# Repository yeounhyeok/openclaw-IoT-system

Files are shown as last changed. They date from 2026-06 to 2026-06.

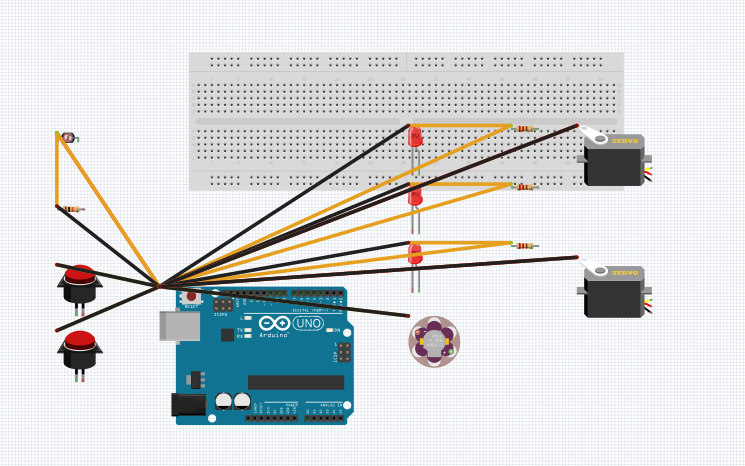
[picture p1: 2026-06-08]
docs/스크린샷 2026-06-02 164702.png

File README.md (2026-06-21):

# OpenClaw Physical Hand - Arduino 회로 프로젝트

제안서의 `OpenClaw Physical Hand: Arduino 기반 원격 버튼 제어 봇`을 실제로 구현하기 위한 Arduino 회로/펌웨어 프로젝트입니다.

> 이 프로젝트는 **실제 하드웨어 직접 제작**을 기준으로 정리되어 있습니다.
> `diagram.json`은 Wokwi에서 동작을 미리 확인하고 싶을 때 쓰는 보조 시뮬레이션 파일이며,
> CDS 부분만 Wokwi에 단순 2핀 CDS 부품이 없어 모듈형 광센서로 대체되어 있습니다.
> 실제 제작에서는 아래 설명대로 **다리 2개짜리 CDS 조도센서 + 분압저항** 구성을 사용합니다.

## 프로젝트 개요

- 메인 보드: Arduino Uno R4 WiFi + HC-05 Bluetooth 모듈
- 입력 디바이스 3종 / 출력 디바이스 4종으로 과제 조건(입력 3종↑ · 출력 3종↑) 충족
- 핵심 기능
  - 버튼으로 알람 토글
  - DHT22로 온습도 표시
  - **CDS 조도센서로 LCD 백라이트 자동 절전(주변이 어두워지면 백라이트 OFF)**
  - 서보모터로 PC 전원 버튼 누르기

## 포함 파일

- `sketch/sketch.ino` : Arduino 펌웨어 (메인 산출물)
- `README.md` : 회로 설명 / 핀맵 / 배선 / 동작 설명
- `docs/circuit_schematic.png` : 전체 연결 schematic 이미지 (보고서/HWP 첨부용)
- `docs/cds_divider.png` : CDS 조도센서 분압 회로 상세도
- `docs/*.svg` : 위 이미지의 벡터 버전 (확대해도 안 깨짐)
- `docs/OpenClaw.fzz` : **Fritzing 프로젝트 파일** (Fritzing에서 바로 열기)
- `docs/OpenClaw.fz` : 위 fzz 안의 스케치 XML (수정/검수용)
- `tools/make_schematic.py` : schematic 이미지 생성 스크립트
- `tools/make_fritzing.py` : Fritzing `.fzz` 생성 스크립트
- `diagram.json` : (선택) Wokwi 미리보기용 회로 배치 파일

## 회로도 (이미지)

보고서/발표 자료에 바로 붙일 수 있는 회로 이미지가 `docs/`에 있습니다.

- `docs/circuit_schematic.png` : Arduino Uno 중심 전체 연결도 (입력 4종 / 출력 4종이 한눈에)
- `docs/cds_divider.png` : 다리 2개짜리 CDS + 10kΩ 분압 회로 상세도

> 이미지는 Python `schemdraw`로 생성했습니다. 수정이 필요하면 아래처럼 재생성하면 됩니다.
> ```
> pip install schemdraw matplotlib
> python tools/make_schematic.py
> ```

## Fritzing 프로젝트 (docs/OpenClaw.fzz)

Fritzing에서 바로 열 수 있는 회로 파일도 포함되어 있습니다.

- 열기: Fritzing 실행 → File → Open → `docs/OpenClaw.fzz`
- 포함 부품(모두 Fritzing 기본 내장 core 부품): Arduino Uno, CDS(photoresistor) + 10k 분압, RGB용 LED 3개 + 220Ω 3개, 푸시버튼 2개, 피에조 부저, 서보 2개
- 배선은 핀맵표와 동일하게 연결되어 있습니다(점대점 배선). 열고 나서 부품을 드래그해 보기 좋게 정렬하면 됩니다.
- **참고**: DHT22 / I2C 1602 LCD 는 Fritzing 기본 core 부품에 없어서(별도 라이브러리 필요) 이 fzz에는 빠져 있습니다. 두 부품을 포함한 전체 구성은 `docs/circuit_schematic.png`(전체 연결도)와 `diagram.json`(Wokwi)에서 확인할 수 있습니다.
- 생성/수정: `python tools/make_fritzing.py` (core 부품의 moduleId·connectorId를 코드에서 직접 지정)

> 이 fzz는 Fritzing core 부품의 공식 moduleId/connectorId를 사용해 생성했고 XML 유효성은 검증했지만,
> 생성 환경에 Fritzing이 없어 화면 렌더링까지는 확인하지 못했습니다.
> 열었을 때 부품이 겹쳐 보이면 드래그로 정렬하면 되고, 혹시 누락/오류가 보이면 알려주세요.

## 입력 디바이스 3종

| # | 디바이스 | 연결 핀 | 역할 |
|---|---|---|---|
| 1 | DHT22 온습도 센서 | D2 | 온도/습도 환경값 입력 |
| 2 | Push Button | D3(ALARM) | 알람 토글 |
| 3 | **CDS 조도센서 (다리 2개)** | A0 | 주변 밝기 입력 → LCD 백라이트 자동 절전 |

## 출력 디바이스 4종

| # | 디바이스 | 연결 핀 | 역할 |
|---|---|---|---|
| 1 | Servo Motor | D9(PC 전원) | PC 전원 버튼 누르기 |
| 2 | 16×2 I2C LCD | A4(SDA), A5(SCL) | 온습도·알람·감지 상태 표시 |
| 3 | RGB LED | D12(R), D5(G), D6(B) | 정상/동작/이벤트/오류/알람 상태 표시 |
| 4 | Piezo Buzzer | D8 | 알림음 / 알람음 출력 |

## 전체 핀맵 (Arduino Uno 기준)

| 핀 | 연결 |
|----|---|
| D2 | DHT22 DATA |
| D3 | ALARM 버튼 (INPUT_PULLUP, 반대편 GND) |
| D5 | RGB LED G (220Ω 경유) |
| D6 | RGB LED B (220Ω 경유) |
| D8 | Buzzer (+) |
| D9 | PC 전원 서보 신호 |
| D12 | RGB LED R (220Ω 경유) |
| A0 | CDS 분압 노드 |
| A4 / A5 | LCD I2C SDA / SCL |
| 5V / GND | 공통 전원 / 접지 |

## CDS 조도센서 배선 (실제 제작 — 중요)

다리 2개짜리 CDS(광저항)는 단독으로 아날로그 값을 못 만들기 때문에 **분압 저항과 함께 분압 회로**로 연결합니다.

```
5V ──[ CDS ]──┬──[ 10kΩ ]── GND
              │
              └──> A0
```

- 밝을 때 : CDS 저항 ↓ → A0 전압(값) ↑
- 어두울 때 : CDS 저항 ↑ → A0 전압(값) ↓
- 코드에서 `analogRead(A0)` 값이 `LCD_DARK_THRESHOLD(=300)`보다 낮아지면 어두운 것으로 판단

> 분압 저항은 10kΩ을 기준으로 하며, 사용하는 CDS 사양에 따라 4.7k~10k 범위로 조정하면 됩니다.
> A0와 GND 사이에 CDS를 두는 반대 배선을 쓰면 밝고/어두움의 값 방향이 뒤집히므로,
> 그 경우 코드의 비교 부등호만 바꿔주면 됩니다.

## LCD 백라이트 자동 절전 기능 (핵심 기능)

스토리: 불을 끄고 잘 때 1602 LCD 백라이트가 너무 밝으면 눈이 부실 수 있으므로, 주변이 어두워지면 LCD 백라이트만 자동으로 끕니다.

- 사용 센서: CDS 조도센서 (다리 2개, A0 분압)
- 어두움 감지: `lcd.noBacklight();` 실행 → 배경 불빛 OFF
- 밝음 감지: `lcd.backlight();` 실행 → 배경 불빛 ON
- LCD 글씨/상태 정보는 유지되고, **배경 불빛만** 꺼지는 방식
- 시연 방법: 손으로 CDS를 가리면 LCD 백라이트가 꺼지고, 손을 떼면 다시 켜짐
- 친환경 IoT 포인트: 사용하지 않는 상황에서 표시장치 전력 소모와 빛 공해를 줄임

## 버튼 / RGB / 부저 동작

- `ALARM TOGGLE` 버튼 : 알람 ON/OFF 토글 (ON이면 부저 3회, RGB 보라)
- RGB LED 상태색
  - 초록 : 정상/대기
  - 보라 : 알람 ON
  - 파랑 : 원격(PC 전원) 명령 실행 / 감지 이벤트
  - 빨강 : DHT 읽기 오류

## 통신 조건 설명

실제 제작에서는 Arduino Uno R4 WiFi를 사용한다고 설명하면 됩니다.

- WiFi: Uno R4 WiFi 내장 무선 기능으로 Home Assistant WSS/HTTP 연동
- Bluetooth: HC-05 모듈로 Android 앱 근거리 제어
- PC 전원 누르기: Android Bluetooth 또는 Home Assistant WebSocket 명령을 받으면 PC 전원 서보가 동작

현재 `sketch/sketch.ino`에는 Uno R4 WiFi의 내장 BLE 코드, HC-05 Bluetooth UART 코드, WiFi 코드, Home Assistant WebSocket/HTTP 코드가 모두 들어가 있습니다. 단, Uno R4 WiFi의 내장 Bluetooth와 내장 WiFi는 같은 무선 모듈/안테나를 공유하므로 같은 순간에 둘을 동시에 켜는 방식은 사용할 수 없습니다.

WiFi와 Android Bluetooth 제어를 한 번에 시연하려면 HC-05 모듈을 추가하면 됩니다. 이 경우 Arduino는 내장 WiFi로 공유기/Home Assistant에 붙고, HC-05는 `Serial1`로 Android 명령을 전달합니다.

### Arduino 설정 플래그

`sketch/sketch.ino` 상단에서 통신 기능을 켜고 끕니다.

```cpp
#define ENABLE_BLE 0
#define ENABLE_HC05 1
#define ENABLE_WIFI 1
#define ENABLE_HA_HTTP 1
#define ENABLE_HA_WS 1
#define HA_USE_SSL 1
#define ENABLE_MQTT 0
```

- `ENABLE_BLE 1`: Uno R4 WiFi 내장 BLE로 Android 제어 사용
- `ENABLE_BLE 0`: Wokwi / 일반 Uno 시뮬레이션용
- `ENABLE_HC05 1`: HC-05 Bluetooth Classic 모듈로 Android 제어 사용
- `ENABLE_HC05 0`: HC-05 미사용
- `ENABLE_WIFI 1`: WiFi 공유기 연결 및 IP/RSSI 상태 확인
- `ENABLE_WIFI 0`: WiFi 연결 미사용
- `ENABLE_HA_HTTP 1`: Home Assistant HTTP REST API 연동 사용
- `ENABLE_HA_HTTP 0`: Home Assistant HTTP 미사용
- `ENABLE_HA_WS 1`: Home Assistant WebSocket으로 명령 이벤트 수신
- `ENABLE_HA_WS 0`: WebSocket 미사용, HTTP polling fallback 사용
- `HA_USE_SSL 1`: `https://` endpoint 사용
- `HA_USE_SSL 0`: 로컬 `http://` endpoint 사용
- `ENABLE_MQTT 1`: Home Assistant MQTT 명령/상태 연동 사용
- `ENABLE_MQTT 0`: MQTT 미사용

시연 모드는 아래처럼 나눕니다.

| 시연 | `ENABLE_BLE` | `ENABLE_HC05` | `ENABLE_WIFI` | `ENABLE_HA_HTTP` | `ENABLE_HA_WS` | `ENABLE_MQTT` |
|---|---|---|---|---|---|---|
| WiFi + HC-05 + HA WSS/HTTP | `0` | `1` | `1` | `1` | `1` | `0` |
| WiFi + HC-05 + HA HTTP polling | `0` | `1` | `1` | `1` | `0` | `0` |
| WiFi + HC-05만 | `0` | `1` | `1` | `0` | `0` | `0` |
| 내장 BLE 단독 시연 | `1` | `0` | `0` | `0` | `0` | `0` |
| WiFi 연결/IP 확인 | `0` | `0` | `1` | `0` | `0` | `0` |
| Home Assistant MQTT 제어 | `0` | `0` | `1` | `0` | `0` | `1` |
| Wokwi / 일반 Uno 시뮬레이션 | `0` | `0` | `0` | `0` | `0` | `0` |

즉, HC-05를 붙이면 과제에서 "WiFi와 Bluetooth가 한 번에 된다"를 같은 업로드로 보여줄 수 있습니다. 단, HC-05는 BLE가 아니라 Bluetooth Classic SPP입니다.

### Android 앱 연동값

내장 BLE를 사용할 때 Android 앱은 BLE Peripheral 이름 `OpenClaw-R4`를 찾아 연결합니다.

| 항목 | 값 |
|---|----|
| Service UUID | `19b10000-e8f2-537e-4f6c-d104768a1214` |
| Command Characteristic UUID | `19b10001-e8f2-537e-4f6c-d104768a1214` |
| Status Characteristic UUID | `19b10002-e8f2-537e-4f6c-d104768a1214` |

Android 앱은 Command Characteristic에 UTF-8 문자열을 write 하면 됩니다.

| 명령 | 동작 |
|---|---|
| `PC_POWER` | PC 전원 버튼 서보 1회 누름 |
| `ALARM_TOGGLE` | 알람 ON/OFF 토글 |
| `ALARM_ON` | 알람 ON |
| `ALARM_OFF` | 알람 OFF |
| `STATUS` | 상태값 갱신 |

Status Characteristic은 아래 같은 문자열을 read/notify 합니다.

```text
alarm=ON,temp=25.0,humidity=55
```

HC-05를 사용할 때 Android 앱은 BLE GATT가 아니라 Bluetooth Classic SPP로 연결합니다.

| 항목 | 값 |
|---|----|
| 장치 이름 | 보통 `HC-05` |
| 기본 PIN | 보통 `1234` 또는 `0000` |
| SPP UUID | `00001101-0000-1000-8000-00805F9B34FB` |
| 전송 방식 | BluetoothSocket output stream에 문자열 전송 |

Android 앱은 아래 명령 문자열을 HC-05로 보내면 됩니다. 줄바꿈(`\n`) 또는 세미콜론(`;`)을 붙여 보내면 가장 안정적입니다.

```text
PC_POWER
ALARM_TOGGLE
ALARM_ON
ALARM_OFF
STATUS
```

예:

```text
PC_POWER\n
```

MIT App Inventor로 앱을 만들 때는 [appinventor/OpenClawRemote.aia](appinventor/OpenClawRemote.aia)를 `Projects → Import project (.aia) from my computer`로 가져오면 됩니다. 수동으로 다시 만들거나 블록을 확인할 때는 [docs/appinventor_openclaw_remote.md](docs/appinventor_openclaw_remote.md)를 참고합니다. 구성은 `Pair HC-05`, `Connect HC-05`, `PC Power`, `Alarm Toggle`, `Alarm On/Off`, `Status`, custom command 입력으로 잡았습니다.

### HC-05 배선

Arduino 코드는 HC-05를 `Serial1`로 읽습니다. Uno R4 WiFi의 USB Serial과 `D0/D1` 하드웨어 Serial은 분리되어 있어서, USB로 Serial Monitor를 보면서 HC-05를 `D0/D1`에 연결해도 됩니다.

| HC-05 핀 | Arduino Uno R4 WiFi | 설명 |
|---|---|---|
| `VCC` | `5V` | 일반 HC-05 breakout 보드는 5V 입력 가능 |
| `GND` | `GND` | 공통 접지 |
| `TXD` | `D0 / RX1` | HC-05가 보내는 데이터 → Arduino 수신 |
| `RXD` | `D1 / TX1` | Arduino가 보내는 데이터 → HC-05 수신 |
| `EN` / `KEY` | 연결 안 함 | AT 설정 모드가 필요할 때만 사용 |
| `STATE` | 연결 안 함 | 연결 상태 확인용, 필수 아님 |

주의할 점:

- `TXD`와 `RXD`는 교차 연결합니다. `TXD -> RX1`, `RXD -> TX1`입니다.
- HC-05 breakout 보드는 `VCC`는 5V를 받아도, `RXD` 신호 입력은 3.3V 권장인 경우가 많습니다.
- Arduino `D1/TX1`에서 HC-05 `RXD`로 가는 선에는 전압 분배를 넣는 것이 안전합니다.
- 전압 분배 예: Arduino `D1/TX1` -- `1kΩ` -- HC-05 `RXD` -- `2kΩ` -- GND.
- HC-05 `TXD`에서 Arduino `D0/RX1`로 가는 선은 보통 바로 연결해도 Arduino가 HIGH로 인식합니다.
- 코드 기본 UART 속도는 `9600` baud입니다. 대부분 HC-05 기본 통신 속도와 같습니다.

### Home Assistant WSS/HTTP 연동값

MQTT broker 없이 Home Assistant API로 직접 연결합니다. HA → Arduino 명령은 `wss://ha.yeoun.org/api/websocket` 상시 연결로 받고, Arduino → HA helper 제어도 가능하면 WebSocket `call_service`로 되돌려 보냅니다. 온습도/상태 엔티티 업로드만 REST API `POST /api/states/...`를 느리게 사용합니다. Home Assistant API는 `Authorization: Bearer TOKEN` 인증이 필요합니다.

현재 Arduino 코드는 공개 엔드포인트 `https://ha.yeoun.org` 기준입니다.

민감정보는 `sketch/arduino_secrets.h`에 넣습니다. GitHub에는 올라가지 않도록 제외되어 있으니, 새 환경에서는 `sketch/arduino_secrets.example.h`를 `sketch/arduino_secrets.h`로 복사한 뒤 값을 채웁니다.

```cpp
#define SECRET_WIFI_SSID "SK_1194_2.4G"
#define SECRET_WIFI_PASSWORD "YOUR_WIFI_PASSWORD"

#define SECRET_HA_HOST "ha.yeoun.org"
#define SECRET_HA_PORT 443
#define SECRET_HA_TOKEN "YOUR_HOME_ASSISTANT_LONG_LIVED_ACCESS_TOKEN"
```

로컬 IP로 직접 붙이고 싶으면 `SECRET_HA_HOST`를 로컬 IP로 바꾸고, `SECRET_HA_PORT 8123`, `HA_USE_SSL 0`으로 바꿉니다.

Arduino가 사용하는 HA 엔티티는 다음과 같습니다.

| 엔티티 | 방향 | 역할 |
|---|---|---|
| `sensor.openclaw_status` | Arduino → HA | 알람/온습도/WiFi 상태 |
| `input_boolean.openclaw_alarm` | HA → Arduino | 대시보드 토글로 알람 ON/OFF |
| `input_boolean.openclaw_pc_power` | HA → Arduino | 대시보드 토글로 PC 전원 서보 1회 누름 |
| `input_button.openclaw_pc_power` | HA → Arduino | 호환용 버튼 helper. 누른 시간이 바뀌면 PC 전원 서보 1회 누름 |
| `input_text.openclaw_command` | HA → Arduino | 예비/디버깅용 문자열 명령 |

HA에서 해야 할 일:

1. 프로필에서 Long-Lived Access Token 생성
2. 설정 → 기기 및 서비스 → Helpers에서 Toggle helper 생성
3. Toggle helper 엔티티 ID를 `input_boolean.openclaw_alarm`으로 맞춤
4. Toggle helper 생성
5. Toggle helper 엔티티 ID를 `input_boolean.openclaw_pc_power`로 맞춤
6. 선택: Text helper를 `input_text.openclaw_command`로 만들면 `PC_POWER`, `ALARM_ON` 같은 문자열 명령도 직접 테스트 가능

Arduino는 `input_boolean.openclaw_alarm` 상태를 따라 알람을 켜고 끕니다. PC 전원은 `input_boolean.openclaw_pc_power`가 `on`이 되면 서보를 1회 누른 뒤 다시 `off`로 돌립니다. 기존에 `input_button.openclaw_pc_power`를 만들어 둔 경우도 호환되며, 버튼 state timestamp가 바뀔 때 서보를 1회 누릅니다. 권장값은 `input_boolean.openclaw_pc_power`입니다. 이미 `on`에 머물러 있으면 다음 `turn_on`에서 `state_changed` 이벤트가 안 나므로 서보가 다시 움직이지 않습니다.

WebSocket이 켜져 있으면 HA 토글/버튼 변경은 `state_changed` 이벤트로 즉시 수신합니다. PC power helper reset과 물리 알람 버튼의 HA 동기화는 WebSocket `call_service`를 우선 사용하고, WS가 끊겼을 때만 HTTP로 fallback합니다. HTTP 요청은 온습도/상태 업로드, fallback helper reset에만 사용하며 명령 직후에는 즉시 status POST를 하지 않습니다. `ENABLE_HA_WS 0`으로 끄면 기존 HTTP polling fallback을 사용합니다.

PC 전원 서보와 부저는 `delay()`로 loop를 막지 않는 비동기 방식입니다. 서보 동작 중 들어온 추가 PC 전원 요청은 최대 1회로 병합해 다음 안정 구간에서 실행합니다. 부저는 서보 펄스와 겹치지 않도록 서보가 끝난 뒤 재생하고, 각 `tone()`에 짧은 duration을 걸어 긴 삐 소리가 남지 않게 합니다. 서보/부저 타이밍 중에는 HTTP/status/DHT 같은 느린 작업을 잠깐 건너뛰어, 네트워크 지연 때문에 물리 출력 박자가 밀리는 현상을 줄입니다.

물리 알람 버튼을 누른 직후에는 로컬 상태를 우선합니다. HA에서 늦게 도착한 이전 WebSocket 이벤트가 알람을 다시 되돌리는 것을 막기 위해 짧은 동기화 구간 동안 반대 상태 이벤트를 무시합니다.

Uno R4 WiFi에서 외부 인터럽트는 D2/D3만 지원합니다. D2는 DHT 센서가 사용하므로, 짧은 버튼 클릭을 안정적으로 잡기 위해 ALARM 버튼은 D3에 연결하고 RGB 빨강은 D12로 옮겼습니다.

### Home Assistant MQTT 연동값

HTTP 대신 MQTT를 사용할 때만 이 옵션을 켭니다. 현재 기본 연결 방식은 HTTP입니다.

```cpp
#define ENABLE_HA_HTTP 0
#define ENABLE_MQTT 1
```

외부 인터넷 접속은 Arduino가 직접 인터넷 API에 붙는 방식보다, 사용자가 인터넷에서 Home Assistant에 접속하고 Home Assistant가 내부 MQTT로 Arduino를 제어하는 구조가 안전합니다.

### 작업 전에 준비할 것

1. Arduino IDE에서 보드를 `Arduino UNO R4 WiFi`로 선택
2. 라이브러리 매니저에서 `LiquidCrystal_I2C`, `DHT11` 설치
3. 동시 시연이 필요하면 HC-05를 `D0/D1`에 연결
4. Android 앱에서 Bluetooth Classic SPP 연결 후 문자열 명령 전송 구현
5. WiFi 시연을 위해 `ENABLE_BLE 0`, `ENABLE_HC05 1`, `ENABLE_WIFI 1`, `ENABLE_HA_HTTP 1`, `ENABLE_HA_WS 1`, `HA_USE_SSL 1`로 둠
6. `sketch/arduino_secrets.h`에 WiFi 비밀번호와 Home Assistant Long-Lived Access Token 입력
7. HA에서 `input_boolean.openclaw_alarm`, `input_boolean.openclaw_pc_power` helper 생성
8. 실제 보드 업로드 전 Wokwi만 돌릴 때는 `ENABLE_BLE 0`, `ENABLE_HC05 0`, `ENABLE_WIFI 0`, `ENABLE_HA_HTTP 0`, `ENABLE_MQTT 0`으로 변경

## 필요 라이브러리 (Arduino IDE)

- `Servo` (기본 내장)
- `Wire` (기본 내장)
- `LiquidCrystal_I2C`
- `DHT11`
- `ArduinoMqttClient` (Home Assistant MQTT 연동을 켤 때만 필요, HTTP 방식에는 불필요)
- `ArduinoBLE` (내장 BLE 단독 시연을 켤 때만 필요)

## 업로드 방법

1. Arduino IDE에서 위 라이브러리 설치
2. 위 핀맵·배선표대로 회로 구성 (CDS는 분압 회로로 연결)
3. `sketch/sketch.ino` 열기
4. 보드를 Arduino Uno (또는 Uno R4 WiFi)로 선택 후 업로드

## (선택) Wokwi에서 미리 보기

1. https://wokwi.com 접속 → Arduino Uno 새 프로젝트 생성
2. `diagram.json` 내용 교체
3. `sketch/sketch.ino` 내용 교체 후 Run
4. 단, Wokwi에는 2핀 CDS가 없어 광센서 모듈로 대체되어 있음 (동작/시연은 동일)

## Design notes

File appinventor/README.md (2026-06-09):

# OpenClaw App Inventor Remote

Import `OpenClawRemote.aia` in MIT App Inventor:

1. Open <https://ai2.appinventor.mit.edu>
2. Select `Projects`
3. Select `Import project (.aia) from my computer`
4. Upload `OpenClawRemote.aia`
5. Pair Android with `HC-05` in Android Bluetooth settings
6. Build/install the app and connect to `HC-05`

The app sends these Bluetooth Classic SPP commands to Arduino:

```text
PC_POWER;
ALARM_TOGGLE;
ALARM_ON;
ALARM_OFF;
STATUS;
```

The semicolon is intentional. The Arduino HC-05 parser treats `;`, `\n`, and `\r` as command terminators.

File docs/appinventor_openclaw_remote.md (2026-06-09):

# OpenClaw MIT App Inventor Bluetooth Remote

이 문서는 Android 휴대폰에서 HC-05 Bluetooth Classic SPP로 OpenClaw Arduino를 조작하는 MIT App Inventor 앱 설계입니다.

Home Assistant 앱은 인터넷 제어용이고, 이 앱은 과제의 Bluetooth 근거리 제어용입니다.

바로 가져다 쓸 때는 [../appinventor/OpenClawRemote.aia](../appinventor/OpenClawRemote.aia)를 MIT App Inventor에서 import합니다. 아래 내용은 앱을 직접 만들거나 import 후 블록을 확인할 때 쓰는 설계 설명입니다.

## 전제

- Arduino: `ENABLE_HC05 1`
- HC-05 baud: `9600`
- Android 설정에서 HC-05를 먼저 페어링
- 기본 PIN은 보통 `1234` 또는 `0000`
- App Inventor: <https://ai2.appinventor.mit.edu>

Arduino가 받는 명령은 줄바꿈(`\n`)으로 끝나면 가장 안정적입니다.

```text
PC_POWER
ALARM_TOGGLE
ALARM_ON
ALARM_OFF
STATUS
```

## Designer 구성

프로젝트 이름 예시: `OpenClawRemote`

### Screen1

권장 속성:

| 속성 | 값 |
|---|---|
| `AppName` | `OpenClaw Remote` |
| `Title` | `OpenClaw Remote` |
| `Sizing` | `Responsive` |
| `AlignHorizontal` | `Center` |

### Visible Components

| 컴포넌트 | 이름 | 주요 속성 |
|---|---|---|
| `Label` | `LabelTitle` | `Text`: `OpenClaw Remote` |
| `Label` | `LabelConnection` | `Text`: `Disconnected` |
| `ListPicker` | `ListPickerConnect` | `Text`: `Connect HC-05` |
| `Button` | `ButtonPcPower` | `Text`: `PC Power` |
| `Button` | `ButtonAlarmToggle` | `Text`: `Alarm Toggle` |
| `Button` | `ButtonAlarmOn` | `Text`: `Alarm On` |
| `Button` | `ButtonAlarmOff` | `Text`: `Alarm Off` |
| `Button` | `ButtonStatus` | `Text`: `Status` |
| `TextBox` | `TextBoxCustom` | `Hint`: `Custom command` |
| `Button` | `ButtonSendCustom` | `Text`: `Send` |
| `Label` | `LabelLastCommand` | `Text`: `Last command: -` |
| `Label` | `LabelStatus` | `Text`: `Status: -` |

배치는 `VerticalArrangement` 안에 넣고, 버튼들은 `HorizontalArrangement`로 2개씩 묶으면 시연 화면이 깔끔합니다.

### Non-visible Components

| 컴포넌트 | 이름 | 주요 속성 |
|---|---|---|
| `BluetoothClient` | `BluetoothClient1` | `DelimiterByte`: `10` |
| `Notifier` | `Notifier1` | 기본값 |
| `Clock` | `ClockStatus` | `TimerInterval`: `300`, `TimerEnabled`: `true` |

`DelimiterByte 10`은 newline `\n`입니다. Arduino가 `Serial1.println()`으로 보내는 상태 응답을 줄 단위로 읽기 위한 설정입니다.

## Blocks 구성

### 1. 연결 목록 표시

`ListPickerConnect.BeforePicking`

```text
set ListPickerConnect.Elements to BluetoothClient1.AddressesAndNames
```

### 2. HC-05 연결

`ListPickerConnect.AfterPicking`

```text
if BluetoothClient1.Connect(ListPickerConnect.Selection)
then
  set LabelConnection.Text to join "Connected: " ListPickerConnect.Selection
  set ListPickerConnect.Text to "Reconnect"
  call Notifier1.ShowAlert("HC-05 connected")
else
  set LabelConnection.Text to "Connection failed"
  call Notifier1.ShowAlert("HC-05 connection failed")
```

연결 실패 시 Android Bluetooth 설정에서 HC-05가 먼저 페어링되어 있는지 확인합니다.

### 3. 공통 명령 전송 Procedure

Procedure 이름: `SendCommand`

인자: `command`

```text
if BluetoothClient1.IsConnected
then
  call BluetoothClient1.SendText(join command "\n")
  set LabelLastCommand.Text to join "Last command: " command
else
  call Notifier1.ShowAlert("Connect HC-05 first")
```

### 4. 버튼 이벤트

`ButtonPcPower.Click`

```text
call SendCommand("PC_POWER")
```

`ButtonAlarmToggle.Click`

```text
call SendCommand("ALARM_TOGGLE")
```

`ButtonAlarmOn.Click`

```text
call SendCommand("ALARM_ON")
```

`ButtonAlarmOff.Click`

```text
call SendCommand("ALARM_OFF")
```

`ButtonStatus.Click`

```text
call SendCommand("STATUS")
```

`ButtonSendCustom.Click`

```text
call SendCommand(TextBoxCustom.Text)
```

### 5. Arduino 상태 수신

`ClockStatus.Timer`

```text
if BluetoothClient1.IsConnected
then
  if BluetoothClient1.BytesAvailableToReceive > 0
  then
    set LabelStatus.Text to BluetoothClient1.ReceiveText(-1)
```

`ReceiveText(-1)`은 `DelimiterByte`를 만날 때까지 읽습니다. `BluetoothClient1.DelimiterByte`가 `10`이어야 합니다.

## 시연 플로우

1. Android Bluetooth 설정에서 `HC-05` 페어링
2. OpenClaw 앱 실행
3. `Connect HC-05` 클릭
4. 목록에서 `HC-05` 선택
5. `Status` 클릭해서 `STATUS alarm=...` 응답 확인
6. `Alarm On`, `Alarm Off`, `PC Power` 버튼 시연

## 문제 해결

| 증상 | 원인/해결 |
|---|---|
| 목록에 HC-05가 안 보임 | Android 설정에서 먼저 페어링 |
| 연결 실패 | HC-05 전원/GND/TX/RX 확인, PIN `1234`/`0000` 확인 |
| 버튼 눌러도 반응 없음 | Arduino `ENABLE_HC05 1`, HC-05 baud `9600`, RX/TX 교차 연결 확인 |
| 글자가 깨짐 | `BluetoothClient1.DelimiterByte 10`, 전송 문자열 끝 `\n`, baud `9600` 확인 |
| STATUS가 안 보임 | `ClockStatus.TimerEnabled true`, `TimerInterval 300`, `ReceiveText(-1)` 확인 |

## 제출 설명 문장

> Android 앱은 MIT App Inventor로 구현했으며, HC-05 Bluetooth Classic SPP를 통해 `PC_POWER`, `ALARM_ON`, `ALARM_OFF`, `STATUS` 등의 문자열 명령을 Arduino `Serial1`로 전송한다. Arduino는 같은 명령 처리 함수를 Home Assistant WebSocket과 HC-05 양쪽에서 공유하므로, 인터넷 제어와 근거리 Bluetooth 제어가 동일한 동작을 수행한다.

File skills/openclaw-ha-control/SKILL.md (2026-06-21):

---
name: openclaw-ha-control
description: Use when controlling or monitoring the OpenClaw Arduino IoT device through Home Assistant at ha.yeoun.org, including PC power servo control, alarm state, temperature, humidity, WiFi status, REST service calls, and WebSocket state observation.
version: 1.0.0
author: Yeounhyeok / Hermes Agent
license: MIT
platforms: [linux, macos, windows]
metadata:
  hermes:
    tags: [home-assistant, arduino, iot, openclaw, smart-home, websocket, rest]
    related_skills: [pc-power-control, yeoun-cloudflare-tunnel-npm, openhue]
---

# OpenClaw Home Assistant Control

Use this skill when the user asks to control or inspect the OpenClaw Arduino device through Home Assistant.

## Connection

- Home Assistant base URL: `https://ha.yeoun.org`
- REST API base: `https://ha.yeoun.org/api`
- WebSocket API: `wss://ha.yeoun.org/api/websocket`
- Authentication: use a Home Assistant long-lived access token from the agent secret store or environment, preferably `HA_TOKEN` or `HOME_ASSISTANT_TOKEN`. In this Hermes profile, `HOME_ASSISTANT_TOKEN` may be set in `~/.hermes/.env`.
- Never write, print, commit, or log the token.
- Arduino command handling is WebSocket-first. REST `/api/states` is mainly used by Arduino for slow status/temperature/humidity uploads.

REST requests require:

```http
Authorization: Bearer <HA_TOKEN>
Content-Type: application/json
```

## Entities

Read-only status from Arduino:

- `sensor.openclaw_status`: main status entity. State is usually `online`; attributes include `light`, `alarm`, `bluetooth`, `wifi_ip`, `wifi_rssi`, `temperature`, and `humidity`.

Controls from Home Assistant to Arduino:

- `input_boolean.openclaw_alarm`: alarm enable/disable toggle.
- `input_boolean.openclaw_pc_power`: momentary PC power request if the toggle helper exists. Turn it `on`; Arduino presses the servo once and resets it to `off`.
- `input_button.openclaw_pc_power`: current working PC power helper. Pressing it changes the timestamp and triggers the servo once; prefer this path when available.
- `input_text.openclaw_command`: fallback/debug text command.

Supported text commands:

- `PC_POWER`
- `ALARM_TOGGLE`
- `ALARM_ON`
- `ALARM_OFF`
- `STATUS`

## Natural Language Mapping

- "PC 켜", "PC 꺼", "컴퓨터 전원 눌러", "전원 버튼 눌러" -> press `input_button.openclaw_pc_power` via `openclaw-pc-power` (current working path).
- "알람 켜", "보안 켜" -> send `ALARM_ON` through `input_text.openclaw_command` and sync `input_boolean.openclaw_alarm`.
- "알람 꺼", "보안 꺼" -> send `ALARM_OFF` through `input_text.openclaw_command` and sync `input_boolean.openclaw_alarm`.
- "상태 확인", "오픈클로 상태", "온습도", "온도", "습도" -> read `sensor.openclaw_status`.

If a PC power request is ambiguous, confirm once before pressing. This command physically actuates a servo connected to a power button.

## Agent Quick Commands

Use the installed one-command wrappers first for fast responses. They load `~/.hermes/.env` themselves and never print the token.

| Intent | Command |
|---|---|
| Full status | `openclaw-status` or `openclaw status` |
| Temperature/humidity | `openclaw-temp` or `openclaw temp` |
| Alarm on | `openclaw-alarm-on` or `openclaw alarm-on` |
| Alarm off | `openclaw-alarm-off` or `openclaw alarm-off` |
| PC power servo press | `openclaw-pc-power` or `openclaw pc-power` |
| Compatibility button press | `openclaw-pc-power-button` or `openclaw pc-power-button` |
| Fallback text command | `openclaw command PC_POWER` / `ALARM_TOGGLE` / `ALARM_ON` / `ALARM_OFF` / `STATUS` |

Implementation lives at `skills/openclaw-ha-control/scripts/openclaw`. Optional local wrappers may point to this script. The script sets `User-Agent: curl/8.5.0` because Cloudflare may block Python urllib's default User-Agent with `403 error code: 1010`.
For setup details, wrapper inventory, and verification commands, see `references/openclaw-cli-setup.md`.
For the alarm-specific control/verification path and the `input_boolean` vs Arduino status pitfall, see `references/alarm-control-path.md`.

PC power commands physically press the power button once. If user intent is ambiguous, confirm once before running `openclaw-pc-power`.

## REST Workflow

Read main status:

```http
GET https://ha.yeoun.org/api/states/sensor.openclaw_status
```

Read temperature and humidity:

```http
GET https://ha.yeoun.org/api/states/sensor.openclaw_status
```

Use these response fields:

```json
{
  "state": "online",
  "attributes": {
    "temperature": 28,
    "humidity": 47
  }
}
```

Press PC power once using the preferred toggle helper:

```http
POST https://ha.yeoun.org/api/services/input_boolean/turn_on

{"entity_id":"input_boolean.openclaw_pc_power"}
```

Press PC power once using the compatibility button helper:

```http
POST https://ha.yeoun.org/api/services/input_button/press

{"entity_id":"input_button.openclaw_pc_power"}
```

Turn alarm on/off. This firmware path is most reliable through `input_text.openclaw_command`; also sync the helper state for dashboard/UI consistency:

```http
POST https://ha.yeoun.org/api/services/input_text/set_value

{"entity_id":"input_text.openclaw_command","value":"ALARM_ON"}
```

```http
POST https://ha.yeoun.org/api/services/input_text/set_value

{"entity_id":"input_text.openclaw_command","value":"ALARM_OFF"}
```

Optional helper sync:

```http
POST https://ha.yeoun.org/api/services/input_boolean/turn_on

{"entity_id":"input_boolean.openclaw_alarm"}
```

```http
POST https://ha.yeoun.org/api/services/input_boolean/turn_off

{"entity_id":"input_boolean.openclaw_alarm"}
```

Fallback command path:

```http
POST https://ha.yeoun.org/api/services/input_text/set_value

{"entity_id":"input_text.openclaw_command","value":"PC_POWER"}
```

## WebSocket Workflow

Use WebSocket for live state observation when the agent needs immediate updates.

1. Connect to `wss://ha.yeoun.org/api/websocket`.
2. Wait for `{"type":"auth_required"}`.
3. Send `{"type":"auth","access_token":"<HA_TOKEN>"}`.
4. Wait for `{"type":"auth_ok"}`.
5. Subscribe to state changes:

```json
{"id":1,"type":"subscribe_events","event_type":"state_changed"}
```

Watch for these `entity_id` values in event data:

- `sensor.openclaw_status`
- `input_boolean.openclaw_alarm`
- `input_boolean.openclaw_pc_power`
- `input_button.openclaw_pc_power`
- `input_text.openclaw_command`

For commands, REST service calls are simplest. If the agent already has an authenticated WebSocket open, it may send Home Assistant `call_service` messages directly.

Press PC power over WebSocket:

```json
{"id":2,"type":"call_service","domain":"input_boolean","service":"turn_on","service_data":{"entity_id":"input_boolean.openclaw_pc_power"}}
```

Press PC power over WebSocket using the compatibility button helper:

```json
{"id":3,"type":"call_service","domain":"input_button","service":"press","service_data":{"entity_id":"input_button.openclaw_pc_power"}}
```

Turn alarm off over WebSocket:

```json
{"id":4,"type":"call_service","domain":"input_boolean","service":"turn_off","service_data":{"entity_id":"input_boolean.openclaw_alarm"}}
```

Use WebSocket to confirm the state changed or to stream updates.

When receiving `sensor.openclaw_status` events, temperature and humidity are in `event.data.new_state.attributes.temperature` and `event.data.new_state.attributes.humidity`.

## Response Style

- Answer the user in Korean unless they ask otherwise.
- For control commands, state exactly what was sent and the resulting HA state if available.
- For status, call the device/system the `IoT 시스템` rather than `OpenClaw` unless referring to entity IDs or the skill/repo name. Say `IoT 시스템 온라인/오프라인`.
- Temperature and humidity are the user's room readings. Say `방 온도`, `방 습도`, or `운혁 님 방` rather than device temperature/humidity.
- Summarize only useful fields: IoT system online/offline, room temperature, room humidity, alarm, WiFi IP, RSSI.
- For temperature/humidity-only requests, answer briefly like `운혁 님 방은 현재 28도, 습도 47%입니다.`
- If HA returns `401` or `403`, say the token/auth path is wrong. If it returns `404`, say the entity ID or helper is missing/mismatched.

## Safety Notes

- Do not expose the HA token.
- Do not assume `input_boolean.openclaw_pc_power` means "turn PC on"; it presses the physical power button once, so it can also shut the PC down.
- Do not use MQTT for the current OpenClaw control path unless the project code is changed back to MQTT. This build uses HA REST plus WebSocket.
- If Cloudflare Access is added later, API calls will also need Access credentials or a bypass rule for trusted clients.

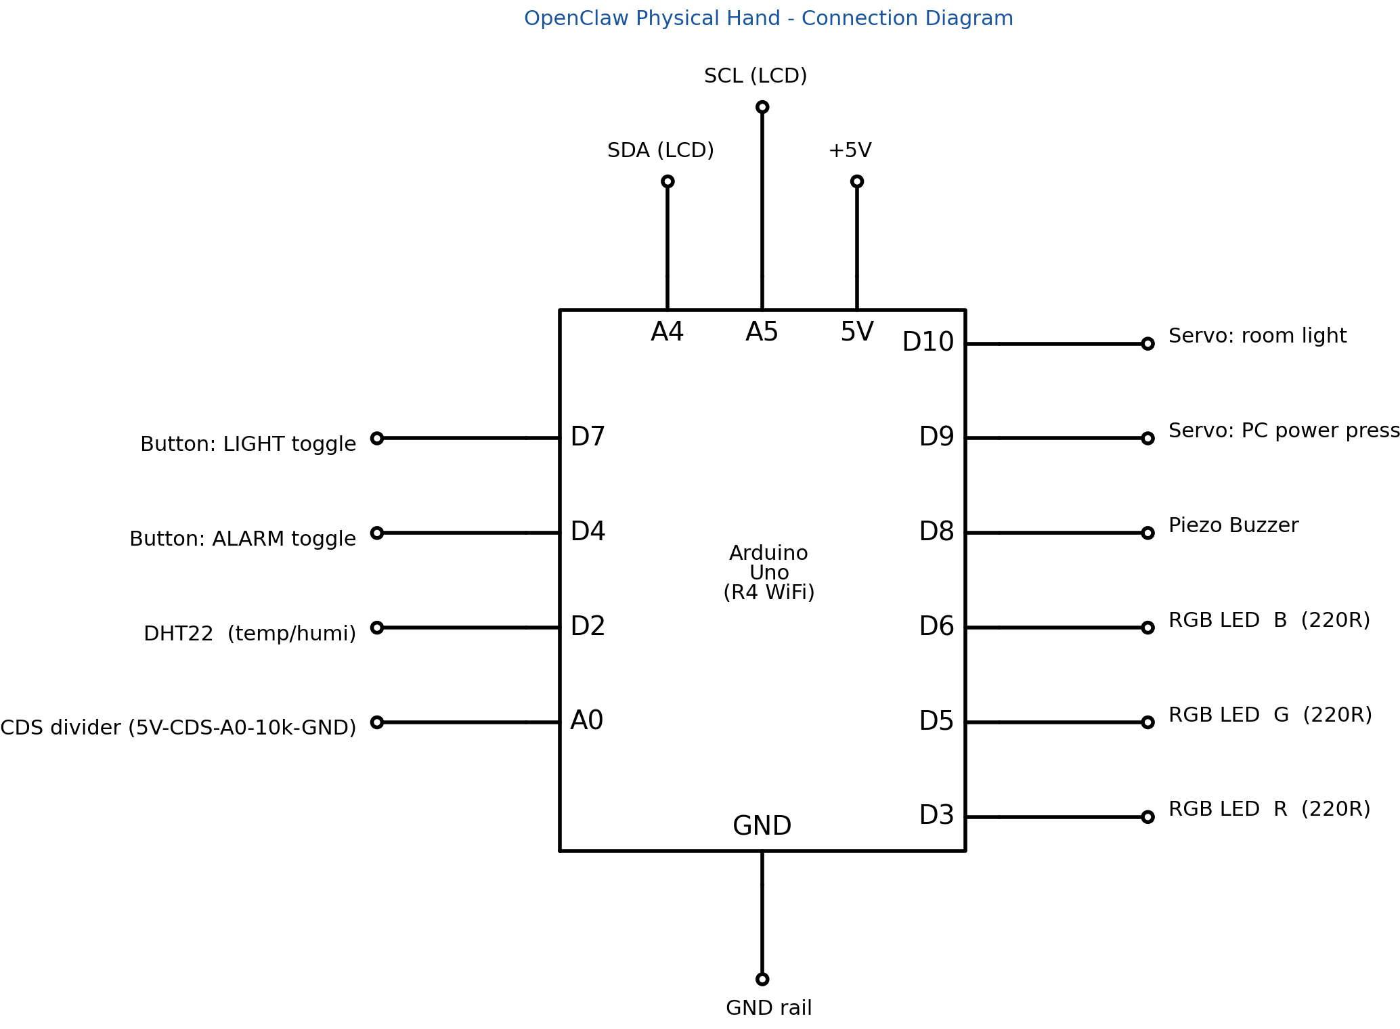
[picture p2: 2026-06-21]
docs/circuit_schematic.png

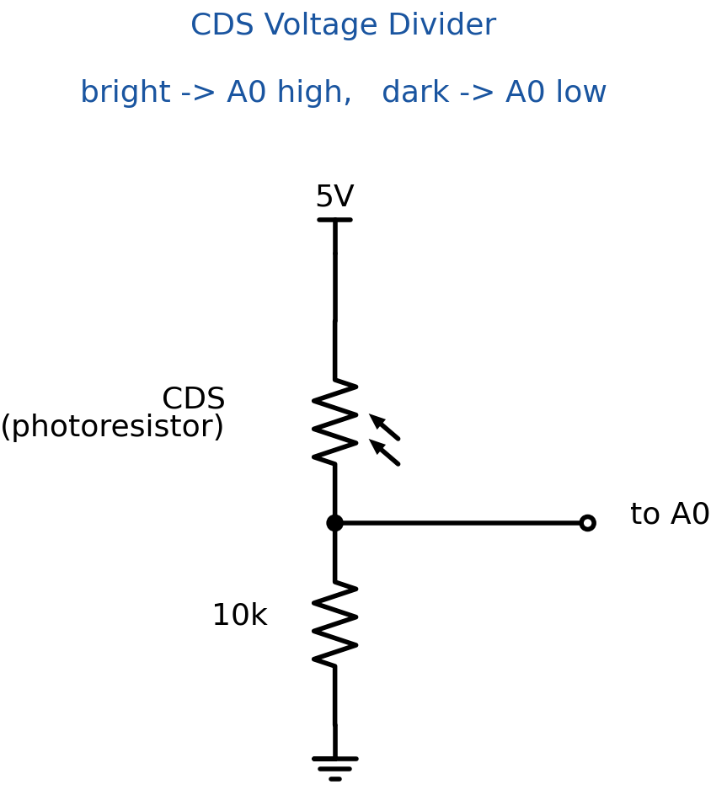
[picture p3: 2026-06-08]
docs/cds_divider.png

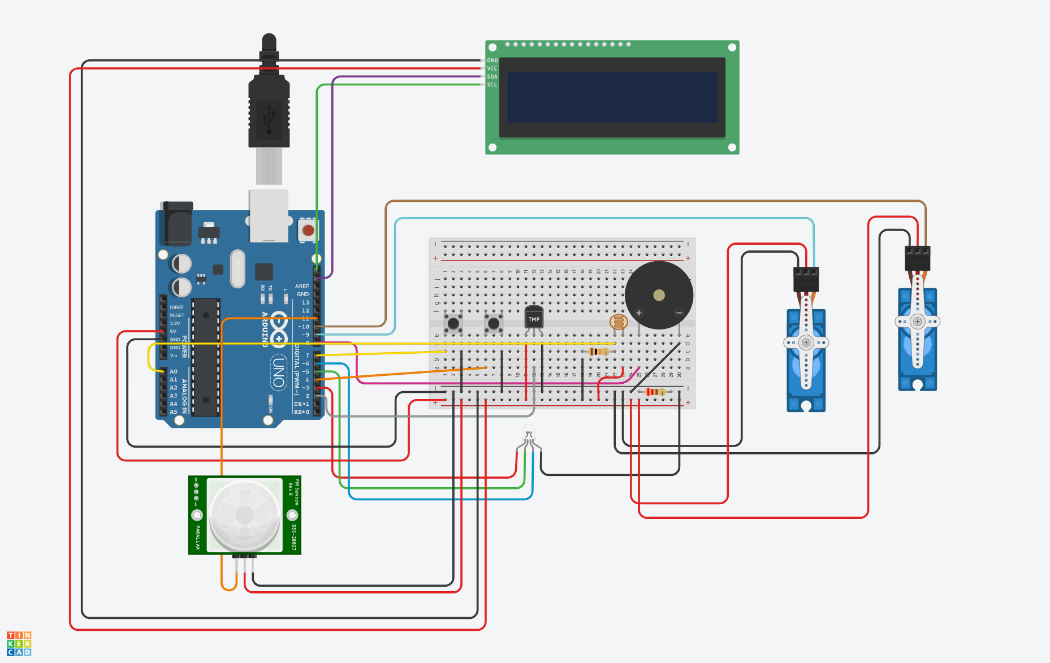
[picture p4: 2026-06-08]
docs/Magnificent Hillar-Elzing.png

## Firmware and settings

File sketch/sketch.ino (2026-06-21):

// OpenClaw Physical Hand - Wokwi demo + Arduino Uno R4 WiFi remote control
// Onboard BLE: Android app writes short text commands to the command characteristic.
// HC-05: Android app writes the same text commands over Bluetooth Classic SPP.
// WiFi: Uno R4 WiFi connects to the local network and reports connection state.
// WSS: Home Assistant WebSocket command path over WiFi.
// HTTP: Home Assistant REST API status path over WiFi.
// MQTT: optional Home Assistant command path over WiFi.
//
// UNO R4 WiFi cannot keep Bluetooth and WiFi active at the same time.
// For simultaneous WiFi + Android Bluetooth control, use HC-05 on Serial1.

#include <Servo.h>
#include <Wire.h>
#include <LiquidCrystal_I2C.h>
#include <DHT11.h>   // DHT11 library: readTemperatureHumidity(temp, humi) -> 0 on success
#include "arduino_secrets.h"

// Built-in BLE demo mode. Set to 0 when using WiFi/MQTT mode.
#ifndef ENABLE_BLE
#define ENABLE_BLE 0
#endif

// HC-05 Bluetooth Classic UART mode. Works with WiFi/MQTT because it uses Serial1.
#ifndef ENABLE_HC05
#define ENABLE_HC05 1
#endif

// WiFi demo mode.
#ifndef ENABLE_WIFI
#define ENABLE_WIFI 1
#endif

// Set ENABLE_HA_HTTP to 1 to connect directly to Home Assistant REST API.
#ifndef ENABLE_HA_HTTP
#define ENABLE_HA_HTTP 1
#endif

// Set ENABLE_HA_WS to 1 for faster Home Assistant command events over WebSocket.
#ifndef ENABLE_HA_WS
#define ENABLE_HA_WS 1
#endif

// Cloudflare/NPM public endpoint uses HTTPS on port 443.
#ifndef HA_USE_SSL
#define HA_USE_SSL 1
#endif

// Set ENABLE_MQTT to 1 if Home Assistant must control the Arduino over WiFi.
#ifndef ENABLE_MQTT
#define ENABLE_MQTT 0
#endif

#if ENABLE_BLE && (ENABLE_WIFI || ENABLE_HA_HTTP || ENABLE_HA_WS || ENABLE_MQTT)
#error "UNO R4 WiFi cannot use built-in BLE and WiFi at the same time. Use HC-05 on Serial1 for simultaneous Bluetooth + WiFi."
#endif

#if (ENABLE_HA_HTTP || ENABLE_HA_WS) && !ENABLE_WIFI
#error "ENABLE_HA_HTTP requires ENABLE_WIFI 1."
#endif

#if ENABLE_HA_WS && !ENABLE_HA_HTTP
#error "ENABLE_HA_WS currently requires ENABLE_HA_HTTP 1 for status posting and helper reset."
#endif

#if ENABLE_MQTT && !ENABLE_WIFI
#error "ENABLE_MQTT requires ENABLE_WIFI 1."
#endif

#if ENABLE_BLE
#include <ArduinoBLE.h>
#endif

#if ENABLE_WIFI || ENABLE_HA_HTTP || ENABLE_HA_WS || ENABLE_MQTT
#include <WiFiS3.h>
#include <string.h>
#endif

#if ENABLE_MQTT
#include <ArduinoMqttClient.h>
#endif

#define DHTPIN 2
#define CDS_SENSOR_PIN A0
#define LCD_DARK_THRESHOLD 300

#define ALARM_BUTTON 3
#define RGB_G 5
#define RGB_B 6
#define BUZZER_PIN 8
#define SERVO_PC_PIN 9
#define RGB_R 12

#define HC05_BAUD 9600
#define HA_HTTP_TIMEOUT_MS 1200
#define HA_WS_READ_TIMEOUT_MS 250
#define HA_FAST_POLL_MS 500
#define HA_COMMAND_POLL_MS 1500
#define HA_STATUS_POST_MS 30000
#define HA_WS_RECONNECT_MS 5000
#define HA_WS_PING_MS 30000
#define HA_LOCAL_ALARM_GRACE_MS 1500
#define PC_SERVO_PRESS_MS 420
#define PC_SERVO_RECOVER_MS 200
#define PC_SERVO_COOLDOWN_MS 180
#define BEEP_ON_MS 90
#define BEEP_OFF_MS 90
#define PC_SERVO_IDLE 0
#define PC_SERVO_PRESSING 1
#define PC_SERVO_RECOVERING 2
#define PC_SERVO_COOLDOWN 3

#if ENABLE_WIFI || ENABLE_HA_HTTP || ENABLE_HA_WS || ENABLE_MQTT
#ifndef SECRET_WIFI_SSID
#define SECRET_WIFI_SSID "YOUR_WIFI_SSID"
#endif
#ifndef SECRET_WIFI_PASSWORD
#define SECRET_WIFI_PASSWORD "YOUR_WIFI_PASSWORD"
#endif

char WIFI_SSID[] = SECRET_WIFI_SSID;
char WIFI_PASSWORD[] = SECRET_WIFI_PASSWORD;
#endif

#if ENABLE_HA_HTTP
#ifndef SECRET_HA_HOST
#define SECRET_HA_HOST "ha.yeoun.org"
#endif
#ifndef SECRET_HA_PORT
#define SECRET_HA_PORT 443
#endif
#ifndef SECRET_HA_TOKEN
#define SECRET_HA_TOKEN "YOUR_HOME_ASSISTANT_LONG_LIVED_ACCESS_TOKEN"
#endif

char HA_HOST[] = SECRET_HA_HOST; // Home Assistant IP/domain, without http:// or https://
int HA_PORT = SECRET_HA_PORT;
char HA_TOKEN[] = SECRET_HA_TOKEN;

const char HA_STATUS_ENTITY[] = "sensor.openclaw_status";
const char HA_COMMAND_ENTITY[] = "input_text.openclaw_command";
const char HA_ALARM_ENTITY[] = "input_boolean.openclaw_alarm";
const char HA_PC_POWER_ENTITY[] = "input_boolean.openclaw_pc_power";
const char HA_PC_POWER_BUTTON_ENTITY[] = "input_button.openclaw_pc_power";
#endif

#if ENABLE_MQTT
char MQTT_BROKER[] = "192.168.0.10"; // Home Assistant / Mosquitto broker IP or domain
int MQTT_PORT = 1883;
char MQTT_USER[] = "YOUR_MQTT_USER";
char MQTT_PASSWORD[] = "YOUR_MQTT_PASSWORD";

const char MQTT_CLIENT_ID[] = "openclaw-r4";
const char MQTT_COMMAND_TOPIC[] = "openclaw/cmd";
const char MQTT_STATUS_TOPIC[] = "openclaw/status";
#endif

Servo pcPowerServo;
LiquidCrystal_I2C lcd(0x27, 16, 2);
DHT11 dht11(DHTPIN);

bool alarmOn = false;
bool lcdBacklightOn = true;
unsigned long lastSensorRead = 0;
unsigned long lastStatusPublish = 0;
unsigned long lastBlePollLog = 0;
unsigned long lastHc05ByteAt = 0;
unsigned long lastWifiStatusLog = 0;
unsigned long lastWifiAttempt = 0;
unsigned long lastHaStatusPost = 0;
unsigned long lastHaCommandPoll = 0;
unsigned long lastHaFastPoll = 0;
unsigned long lastHaWsReconnect = 0;
unsigned long lastHaWsPing = 0;
unsigned long lastMqttAttempt = 0;
unsigned long lastAlarmButtonEvent = 0;
unsigned long lastLocalAlarmChangeAt = 0;
unsigned long pcPowerServoPhaseAt = 0;
unsigned long beepPhaseAt = 0;
int lastAlarmButtonState = HIGH;
float lastTemperature = NAN;
float lastHumidity = NAN;
bool wifiWasConnected = false;
String hc05Buffer = "";
String lastHaCommand = "";
String lastHaAlarmState = "";
String lastHaPcPowerButtonState = "";
bool pendingHaStatusPost = false;
bool pendingHaAlarmSync = false;
bool pendingHaPcPowerReset = false;
bool beepToneOn = false;
bool pcPowerServoQueued = false;
byte pcPowerServoState = PC_SERVO_IDLE;
byte pcPowerBeepsAfterServo = 0;
byte beepPulsesRemaining = 0;
byte haFastPollStep = 0;
volatile byte alarmButtonInterruptCount = 0;
bool haWsSubscribed = false;
int haWsNextId = 1;

#if ENABLE_BLE
BLEService openClawService("19b10000-e8f2-537e-4f6c-d104768a1214");
BLEStringCharacteristic commandCharacteristic(
  "19b10001-e8f2-537e-4f6c-d104768a1214",
  BLEWrite,
  40
);
BLEStringCharacteristic statusCharacteristic(
  "19b10002-e8f2-537e-4f6c-d104768a1214",
  BLERead | BLENotify,
  96
);
#endif

#if ENABLE_MQTT
WiFiClient wifiClient;
MqttClient mqttClient(wifiClient);
#endif

#if ENABLE_HA_WS
#if HA_USE_SSL
WiFiSSLClient haWsClient;
#else
WiFiClient haWsClient;
#endif
#endif

void setRgb(bool r, bool g, bool b) {
  digitalWrite(RGB_R, r ? HIGH : LOW);
  digitalWrite(RGB_G, g ? HIGH : LOW);
  digitalWrite(RGB_B, b ? HIGH : LOW);
}

void beep(int count) {
  if (count <= 0) {
    return;
  }

  byte requested = (byte)(count > 8 ? 8 : count);
  if (beepToneOn) {
    noTone(BUZZER_PIN);
    beepToneOn = false;
  }
  beepPulsesRemaining = requested;
  beepPhaseAt = millis() - BEEP_OFF_MS;
}

void stopBeeper() {
  if (beepToneOn) {
    noTone(BUZZER_PIN);
  }
  beepToneOn = false;
  beepPulsesRemaining = 0;
  beepPhaseAt = 0;
}

bool isBeeperBusy() {
  return beepToneOn || beepPulsesRemaining > 0;
}

void pollBeeper() {
  if (beepPulsesRemaining == 0 && !beepToneOn) {
    return;
  }

  unsigned long now = millis();
  if (!beepToneOn && now - beepPhaseAt >= BEEP_OFF_MS) {
    tone(BUZZER_PIN, 1200, BEEP_ON_MS);
    beepToneOn = true;
    beepPhaseAt = now;
  } else if (beepToneOn && now - beepPhaseAt >= BEEP_ON_MS) {
    noTone(BUZZER_PIN);
    beepToneOn = false;
    beepPhaseAt = now;
    if (beepPulsesRemaining > 0) {
      beepPulsesRemaining--;
    }
    if (beepPulsesRemaining == 0) {
      beepPhaseAt = 0;
    }
  }
}

void pressServoOnce(Servo &servo) {
  if (pcPowerServoState != PC_SERVO_IDLE) {
    pcPowerServoQueued = true;
    Serial.println("PC power servo busy, queued once");
    return;
  }

  stopBeeper();
  servo.write(59);
  pcPowerServoState = PC_SERVO_PRESSING;
  pcPowerServoPhaseAt = millis();
}

bool isPcPowerServoBusy() {
  return pcPowerServoState != PC_SERVO_IDLE;
}

void pollPcPowerServo() {
  if (pcPowerServoState == PC_SERVO_IDLE) {
    return;
  }

  unsigned long now = millis();
  if (pcPowerServoState == PC_SERVO_PRESSING && now - pcPowerServoPhaseAt >= PC_SERVO_PRESS_MS) {
    pcPowerServo.write(0);
    pcPowerServoState = PC_SERVO_RECOVERING;
    pcPowerServoPhaseAt = now;
    return;
  }

  if (pcPowerServoState == PC_SERVO_RECOVERING && now - pcPowerServoPhaseAt >= PC_SERVO_RECOVER_MS) {
    setRgb(alarmOn, !alarmOn, alarmOn); // purple if alarm armed, green otherwise
    pcPowerServoState = PC_SERVO_COOLDOWN;
    pcPowerServoPhaseAt = now;
    return;
  }

  if (pcPowerServoState == PC_SERVO_COOLDOWN && now - pcPowerServoPhaseAt >= PC_SERVO_COOLDOWN_MS) {
    pcPowerServoState = PC_SERVO_IDLE;
    if (pcPowerServoQueued) {
      pcPowerServoQueued = false;
      pressServoOnce(pcPowerServo);
      pcPowerBeepsAfterServo = 2;
      return;
    }

    if (pcPowerBeepsAfterServo > 0) {
      beep(pcPowerBeepsAfterServo);
      pcPowerBeepsAfterServo = 0;
    }
  }
}

String buildStatusMessage() {
  String status = "alarm=";
  status += alarmOn ? "ON" : "OFF";

#if ENABLE_HC05
  status += ",bt=HC05";
#endif

#if ENABLE_WIFI || ENABLE_HA_HTTP || ENABLE_MQTT
  status += ",wifi=";
  status += WiFi.status() == WL_CONNECTED ? "ON" : "OFF";
#endif

  if (!isnan(lastTemperature) && !isnan(lastHumidity)) {
    status += ",temp=";
    status += String(lastTemperature, 1);
    status += ",humidity=";
    status += String(lastHumidity, 0);
  }

  return status;
}

void updateRemoteStatus();

void pressPcPowerByRemoteCommand(const char *source) {
  Serial.print("PC power servo command from ");
  Serial.println(source);

  lcd.clear();
  lcd.setCursor(0, 0);
  lcd.print("PC Power Press");
  lcd.setCursor(0, 1);
  lcd.print(source);
  lcd.print(" cmd");

  setRgb(false, false, true); // blue: remote command executing
  pressServoOnce(pcPowerServo);
  pcPowerBeepsAfterServo = 2;
}

void setAlarm(bool enabled, bool pressPcPower, const char *source) {
  alarmOn = enabled;

  lcd.clear();
  lcd.setCursor(0, 0);
  lcd.print(alarmOn ? "Alarm ON" : "Alarm OFF");
  lcd.setCursor(0, 1);

  if (pressPcPower) {
    lcd.print("PC Power Press");
    setRgb(false, false, true); // blue: PC power command executing
    pressServoOnce(pcPowerServo);
    pcPowerBeepsAfterServo = 2;
  } else {
    lcd.print(source);
    lcd.print(" cmd");
  }

  if (alarmOn) {
    setRgb(true, false, true); // purple: alarm armed
    beep(3);
  } else {
    setRgb(false, true, false); // green: normal
    beep(1);
  }
}

void toggleAlarm() {
  setAlarm(!alarmOn, false, "Button");
}

void onAlarmButtonInterrupt() {
  if (alarmButtonInterruptCount < 10) {
    alarmButtonInterruptCount++;
  }
}

void handleAlarmButtonEvent() {
  Serial.println("ALARM button event");
  toggleAlarm();
  lastLocalAlarmChangeAt = millis();
  lastHaAlarmState = alarmOn ? "on" : "off";
#if ENABLE_HA_HTTP
  pendingHaAlarmSync = true;
#endif
  updateRemoteStatus();
}

void pollAlarmButton() {
  int currentState = digitalRead(ALARM_BUTTON);
  bool fallingEdge = lastAlarmButtonState == HIGH && currentState == LOW;

  noInterrupts();
  byte interruptCount = alarmButtonInterruptCount;
  alarmButtonInterruptCount = 0;
  interrupts();

  bool interruptEdge = interruptCount > 0;
  unsigned long now = millis();

  if ((fallingEdge || interruptEdge) && now - lastAlarmButtonEvent > 250) {
    lastAlarmButtonEvent = now;
    handleAlarmButtonEvent();
  }

  lastAlarmButtonState = currentState;
}

bool handleRemoteCommand(String command, const char *source) {
  command.trim();
  command.toUpperCase();
  command.replace(' ', '_');
  command.replace('-', '_');

  if (command == "PC_POWER" || command == "PC" || command == "POWER") {
    pressPcPowerByRemoteCommand(source);
  } else if (command == "ALARM_TOGGLE" || command == "ALARM") {
    setAlarm(!alarmOn, false, source);
  } else if (command == "ALARM_ON") {
    setAlarm(true, false, source);
  } else if (command == "ALARM_OFF") {
    setAlarm(false, false, source);
  } else if (command == "STATUS") {
    // Only refresh the BLE/MQTT status payload.
  } else {
    lcd.clear();
    lcd.setCursor(0, 0);
    lcd.print("Unknown cmd");
    lcd.setCursor(0, 1);
    lcd.print(command.substring(0, 16));
    setRgb(true, false, false);
    beep(1);
    return false;
  }

  Serial.print(source);
  Serial.print(" command: ");
  Serial.println(command);
  updateRemoteStatus();
  return true;
}

void updateLcdBacklightByCdsSensor() {
  int lightValue = analogRead(CDS_SENSOR_PIN);

  // Real wiring: 5V -- CDS -- A0 -- 10k resistor -- GND (voltage divider).
  // Bright -> CDS resistance low -> A0 high value.
  // Dark   -> CDS resistance high -> A0 low value.
  if (lightValue < LCD_DARK_THRESHOLD && lcdBacklightOn) {
    lcd.noBacklight();
    lcdBacklightOn = false;
  } else if (lightValue >= LCD_DARK_THRESHOLD && !lcdBacklightOn) {
    lcd.backlight();
    lcdBacklightOn = true;
  }
}

void showTemperatureHumidity() {
  // DHT11 (Dhruba Saha) library: readTemperatureHumidity(temp, humi) returns 0 on success.
  int temperature = 0, humidity = 0;
  int result = dht11.readTemperatureHumidity(temperature, humidity);
  if (result == 0) {
    lastTemperature = (float)temperature;
    lastHumidity = (float)humidity;
    Serial.print("temperature:");
    Serial.print(temperature);
    Serial.print(" humidity:");
    Serial.println(humidity);
  } else {
    Serial.print("DHT Error: ");
    Serial.println(DHT11::getErrorString(result));
  }

  // No valid reading yet (still warming up on first seconds, or DATA not on pin 2).
  if (isnan(lastTemperature) || isnan(lastHumidity)) {
    lcd.clear();
    lcd.setCursor(0, 0);
    lcd.print("DHT warming up");
    return;
  }

  lcd.clear();
  lcd.setCursor(0, 0);
  lcd.print("T:");
  lcd.print(lastTemperature, 1);
  lcd.print("C H:");
  lcd.print(lastHumidity, 0);
  lcd.print("%");

  lcd.setCursor(0, 1);
  lcd.print(alarmOn ? "Alarm:ON" : "Alarm:OFF");
}

#if ENABLE_BLE
void setupBle() {
  if (!BLE.begin()) {
    Serial.println("BLE start failed");
    lcd.clear();
    lcd.setCursor(0, 0);
    lcd.print("BLE failed");
    setRgb(true, false, false);
    return;
  }

  BLE.setLocalName("OpenClaw-R4");
  BLE.setDeviceName("OpenClaw-R4");
  BLE.setAdvertisedService(openClawService);

  openClawService.addCharacteristic(commandCharacteristic);
  openClawService.addCharacteristic(statusCharacteristic);
  BLE.addService(openClawService);

  commandCharacteristic.setValue("");
  statusCharacteristic.setValue(buildStatusMessage());

  BLE.advertise();
  Serial.println("BLE advertising: OpenClaw-R4");
}

void pollBle() {
  BLE.poll();

  if (commandCharacteristic.written()) {
    handleRemoteCommand(commandCharacteristic.value(), "BLE");
  }

  if (millis() - lastBlePollLog > 15000) {
    BLEDevice central = BLE.central();
    if (central) {
      Serial.print("BLE central connected: ");
      Serial.println(central.address());
    }
    lastBlePollLog = millis();
  }
}
#endif

#if ENABLE_HC05
void setupHc05() {
  Serial1.begin(HC05_BAUD);
  Serial.println("HC-05 Bluetooth UART ready on Serial1");
  Serial1.println("OpenClaw ready");
}

void sendHc05Status(const String &status) {
  Serial1.print("STATUS ");
  Serial1.println(status);
}

void processHc05Buffer() {
  hc05Buffer.trim();
  if (hc05Buffer.length() == 0) {
    return;
  }

  String command = hc05Buffer;
  hc05Buffer = "";
  handleRemoteCommand(command, "HC05");
}

void pollHc05() {
  while (Serial1.available() > 0) {
    char ch = (char)Serial1.read();
    lastHc05ByteAt = millis();

    if (ch == '\n' || ch == '\r' || ch == ';') {
      processHc05Buffer();
    } else if (hc05Buffer.length() < 40) {
      hc05Buffer += ch;
    } else {
      hc05Buffer = "";
      Serial.println("HC-05 command too long, cleared buffer");
    }
  }

  if (hc05Buffer.length() > 0 && millis() - lastHc05ByteAt > 200) {
    processHc05Buffer();
  }
}
#endif

#if ENABLE_WIFI || ENABLE_HA_HTTP || ENABLE_MQTT
bool hasWifiCredentials() {
  return strlen(WIFI_SSID) > 0 && strcmp(WIFI_SSID, "YOUR_WIFI_SSID") != 0;
}

void setupWifi() {
  if (!hasWifiCredentials()) {
    Serial.println("WiFi skipped: fill WIFI_SSID/WIFI_PASSWORD first");
    lcd.clear();
    lcd.setCursor(0, 0);
    lcd.print("WiFi config need");
    lcd.setCursor(0, 1);
    lcd.print("BT still ready");
    return;
  }

  Serial.print("Connecting WiFi: ");
  Serial.println(WIFI_SSID);
  WiFi.begin(WIFI_SSID, WIFI_PASSWORD);
  lastWifiAttempt = millis();
}

void pollWifi() {
  if (!hasWifiCredentials()) {
    return;
  }

  int status = WiFi.status();
  bool connected = status == WL_CONNECTED;

  if (!connected && millis() - lastWifiAttempt > 10000) {
    Serial.print("Reconnecting WiFi: ");
    Serial.println(WIFI_SSID);
    WiFi.begin(WIFI_SSID, WIFI_PASSWORD);
    lastWifiAttempt = millis();
  }

  if (connected && !wifiWasConnected) {
    IPAddress ip = WiFi.localIP();
    Serial.print("WiFi connected, IP=");
    Serial.println(ip);

    lcd.clear();
    lcd.setCursor(0, 0);
    lcd.print("WiFi connected");
    lcd.setCursor(0, 1);
    lcd.print(ip);
  } else if (!connected && wifiWasConnected) {
    Serial.println("WiFi disconnected");
  }

  if (connected && millis() - lastWifiStatusLog > 30000) {
    Serial.print("WiFi RSSI=");
    Serial.println(WiFi.RSSI());
    lastWifiStatusLog = millis();
  }

  wifiWasConnected = connected;
}
#endif

#if ENABLE_HA_HTTP
bool hasHaHttpConfig() {
  return strlen(HA_HOST) > 0
    && strcmp(HA_HOST, "192.168.45.10") != 0
    && strcmp(HA_HOST, "YOUR_HOME_ASSISTANT_IP") != 0
    && strlen(HA_TOKEN) > 0
    && strcmp(HA_TOKEN, "YOUR_HOME_ASSISTANT_LONG_LIVED_ACCESS_TOKEN") != 0;
}

String jsonEscape(String value) {
  value.replace("\\", "\\\\");
  value.replace("\"", "\\\"");
  value.replace("\n", "\\n");
  value.replace("\r", "");
  return value;
}

bool readHaHttpResponse(Client &client, int &statusCode, String &body) {
  unsigned long deadline = millis() + HA_HTTP_TIMEOUT_MS;

  while (!client.available() && millis() < deadline) {
    delay(5);
  }

  if (!client.available()) {
    Serial.println("HA HTTP timeout waiting for response");
    return false;
  }

  String statusLine = client.readStringUntil('\n');
  statusLine.trim();
  int firstSpace = statusLine.indexOf(' ');
  int secondSpace = statusLine.indexOf(' ', firstSpace + 1);
  if (firstSpace > 0 && secondSpace > firstSpace) {
    statusCode = statusLine.substring(firstSpace + 1, secondSpace).toInt();
  } else {
    statusCode = 0;
  }

  while (client.connected() && millis() < deadline) {
    String header = client.readStringUntil('\n');
    header.trim();
    if (header.length() == 0) {
      break;
    }
  }

  body = "";
  while (millis() < deadline) {
    while (client.available()) {
      body += (char)client.read();
      if (body.length() > 900) {
        body.remove(0, body.length() - 900);
      }
    }
    if (!client.connected()) {
      break;
    }
    delay(5);
  }

  return statusCode >= 200 && statusCode < 300;
}

bool sendHaHttpRequest(const char *method, const String &path, const String &payload, int &statusCode, String &body) {
  if (!hasHaHttpConfig()) {
    Serial.println("HA HTTP skipped: fill HA_HOST/HA_TOKEN first");
    return false;
  }

  if (WiFi.status() != WL_CONNECTED) {
    return false;
  }

#if HA_USE_SSL
  WiFiSSLClient client;
#else
  WiFiClient client;
#endif

  client.setTimeout(HA_HTTP_TIMEOUT_MS);
  if (!client.connect(HA_HOST, HA_PORT)) {
    Serial.println("HA HTTP connect failed");
    return false;
  }

  client.print(method);
  client.print(" ");
  client.print(path);
  client.println(" HTTP/1.1");
  client.print("Host: ");
  client.print(HA_HOST);
  client.print(":");
  client.println(HA_PORT);
  client.print("Authorization: Bearer ");
  client.println(HA_TOKEN);
  client.println("Content-Type: application/json");
  client.println("Connection: close");
  client.print("Content-Length: ");
  client.println(payload.length());
  client.println();
  client.print(payload);

  bool ok = readHaHttpResponse(client, statusCode, body);
  client.stop();

  if (!ok) {
    Serial.print("HA HTTP ");
    Serial.print(method);
    Serial.print(" ");
    Serial.print(path);
    Serial.print(" failed, status=");
    Serial.println(statusCode);
  }

  return ok;
}

String buildHaStatusPayload() {
  String payload = "{\"state\":\"online\",\"attributes\":{";
  payload += "\"alarm\":\"";
  payload += alarmOn ? "on" : "off";
  payload += "\",\"bluetooth\":\"hc05\"";

  if (WiFi.status() == WL_CONNECTED) {
    payload += ",\"wifi_ip\":\"";
    payload += WiFi.localIP().toString();
    payload += "\",\"wifi_rssi\":";
    payload += WiFi.RSSI();
  }

  if (!isnan(lastTemperature) && !isnan(lastHumidity)) {
    payload += ",\"temperature\":";
    payload += String(lastTemperature, 1);
    payload += ",\"humidity\":";
    payload += String(lastHumidity, 0);
  }

  payload += ",\"friendly_name\":\"OpenClaw Status\"}}";
  return payload;
}

void postHaStatus() {
  int statusCode = 0;
  String body = "";
  String path = String("/api/states/") + HA_STATUS_ENTITY;
  if (sendHaHttpRequest("POST", path, buildHaStatusPayload(), statusCode, body)) {
    Serial.println("HA status posted");
  }
}
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
void loop() {
  pollPcPowerServo();
  pollBeeper();
  pollAlarmButton();

  if (isPcPowerServoBusy() || isBeeperBusy()) {
    return;
  }

  updateLcdBacklightByCdsSensor();

#if ENABLE_BLE
  pollBle();
#endif

#if ENABLE_HC05
  pollHc05();
#endif

#if ENABLE_WIFI || ENABLE_HA_HTTP || ENABLE_MQTT
  pollWifi();
#endif

#if ENABLE_HA_WS
  pollHaWs();
#endif

  pollPcPowerServo();
  pollBeeper();

  if (isPcPowerServoBusy() || isBeeperBusy()) {
    return;
  }

#if ENABLE_HA_HTTP
  pollHaHttp();
#endif

#if ENABLE_MQTT
  pollMqtt();
#endif

  if (millis() - lastSensorRead > 3000) {
    showTemperatureHumidity();
    lastSensorRead = millis();
  }

  if (millis() - lastStatusPublish > 10000) {
    updateRemoteStatus();
    lastStatusPublish = millis();
  }
}

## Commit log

2026-06-08 feat: add OpenClaw HA and Bluetooth Arduino project
    [OpenClaw.fz, OpenClaw.fzz]
2026-06-09 fix: improve HA websocket responsiveness
    [sketch.ino]
2026-06-09 fix: stabilize pc power servo timing
    [sketch.ino]
2026-06-09 fix: stabilize buzzer timing
    [sketch.ino]
2026-06-09 fix: OpenClaw HA 전원 버튼 스킬 경로 수정
2026-06-09 fix: OpenClaw 알람 제어 경로 수정
2026-06-09 docs: IoT 시스템 상태 표현 정정
2026-06-20 fix: PIR 인체감지 센서 제거 (실제 기기 미탑재)
    실제 제작 기기에 PIR 모션 센서가 없어 관련 코드/문서를 모두 제거.
    입력 디바이스 4종 -> 3종(DHT22, 버튼, CDS)으로 정정.
    - sketch.ino: PIR_PIN, lastPirState, motion 엔티티/토픽, postHaMotion(),
    pendingHaMotionOn, 상태 문자열·HA payload의 motion 필드, loop의 PIR 감지 블록 제거
    - diagram.json: wokwi-pir-motion-sensor 부품 및 연결 3개 제거
    - README.md: 입력 3종 정정, 핀맵(D11)·PIR 섹션·HA motion 엔티티·상태 예시 정리
    - make_schematic.py: D11 PIR 핀 제거 후 circuit_schematic 재생성
    - test_sketch_static.ps1: motion 관련 단언 제거
    - op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
    [sketch.ino]
2026-06-20 docs: OpenClaw 프로젝트 결과보고서 pptx 추가
    오픈소스HW 결과보고서 양식에 OpenClaw Physical Hand 내용 작성(PIR 제외).
    사진/시연 영상/유튜브/시스템 구성도 및 학번·이름은 추후 직접 채움.
2026-06-21 fix: tune pc servo press angle
    [sketch.ino]
